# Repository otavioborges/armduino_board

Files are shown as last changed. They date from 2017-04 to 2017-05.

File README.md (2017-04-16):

# ARMduino

ARMduino is an open-source + open-hardware project. Created to be a stepping stone from Arduino development boards to ARM development.

The board feature the same pinout as an Arduino UNO&trade; and same voltage levels on target.

## Board Description

### Power source

The board feature automatic source selection using a LM385 and P-MOSFET (same arrangement as Arduino UNO&trade;). External power range goes from 6~30VDC. Max current supported 0.5A.

### Programmer/Debugger

A MKL26Z32VFM4, using an adapted [DAPLink](https://github.com/mbedmicro/DAPLink) source-code (available on https://bitbucket.org/otavioborges/daplink-if, is used as programmer/debugger through openOCD interface.

### Target

The NXP's MKE02Z64VLD4 replaces the usual ATMEGA8U2 from Arduino. Providing:
 * Enhanced operation frequency (up to 20MHz Bus and core);
 * More flexibility on pin muxing (available on [KE02 Sub-family Data Sheet](http://www.nxp.com/assets/documents/data/en/data-sheets/MKE02P64M20SF0.pdf);
 * SPI, I2C, UART, PWM and ADC peripheral access through break-out connections;
 * I/O signal and periodic interrupts;
 * Debugging capabilities, using MKL26, GDB, DAPLink and openOCD;
 * Up to two breakpoints;
 
### Pinout

The same pin voltage and placement used in Arduino UNO&trade; is available. Furthermore, as NXP MCU provide a range of pin-multiplexing pin-assignment can be altered to fit user's desire.

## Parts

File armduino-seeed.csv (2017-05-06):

Part/Designator | Manufacture Part Number/Seeed SKU | Quantity
S1 | SKHHAJA010 | 1
C1, C6, C11, C12, C15 | GRM21BR71E104KA01L | 5
R4, R9, R11, R13, R14, R19 | RC0805FR-0710KL | 6
C3, C4 | 106CKR063M | 2
IOH | 61301011821 | 1
R1, R6, R8, R15, R16, R17, R20 | RC0805JR-07120RL | 7
R5, R12 | RC0805FR-071M02L | 2
D1 | VSSA210-M3/5AT | 1
C5, C20 | GRM216R71H102KA01D | 2
C9, C10, C17 | GRM21BR61C105KA01L | 3
C18 | GRM216R71H222JA01D | 1
Q2 | ABLS-5.000MHZ-B4-T | 1
R7, R10 | RC0805JR-0720KL | 2
C13, C14, C16, C19 | GRM1885C1H220JA01D | 4
C2 | C2012X7R1H334K125AA | 1
R2, R3 | ERJ-6ENF33R0V | 2
ICSP1, ICSP2 | 4-146262-1 | 2
R18 | ERJ-6GEYJ472V | 1
AD | 929870-01-06-RA | 1
IC1 | LD1117DT50TR | 1
Q3 | ABL-8.000MHZ-B2 | 1
IOL, POWER | 960108-6303-AR | 2
LED1 | 150080BS75000 | 1
Q1 | FDN360P | 1
POWER_LED | APT2012SGC | 1
IC3 | IFX1117ME V33 | 1
IC2 | LM358DT | 1
U2 | MKE02Z64VLD4 | 1
U1 | MKL26Z128VFM4 | 1
X1 | PJ-002A | 1
FUSE1 | 0ZCG0050AF2C | 1
X2 | 61400416121 | 1
CONN, RUN, RX, TX, USB | APT2012YC | 5

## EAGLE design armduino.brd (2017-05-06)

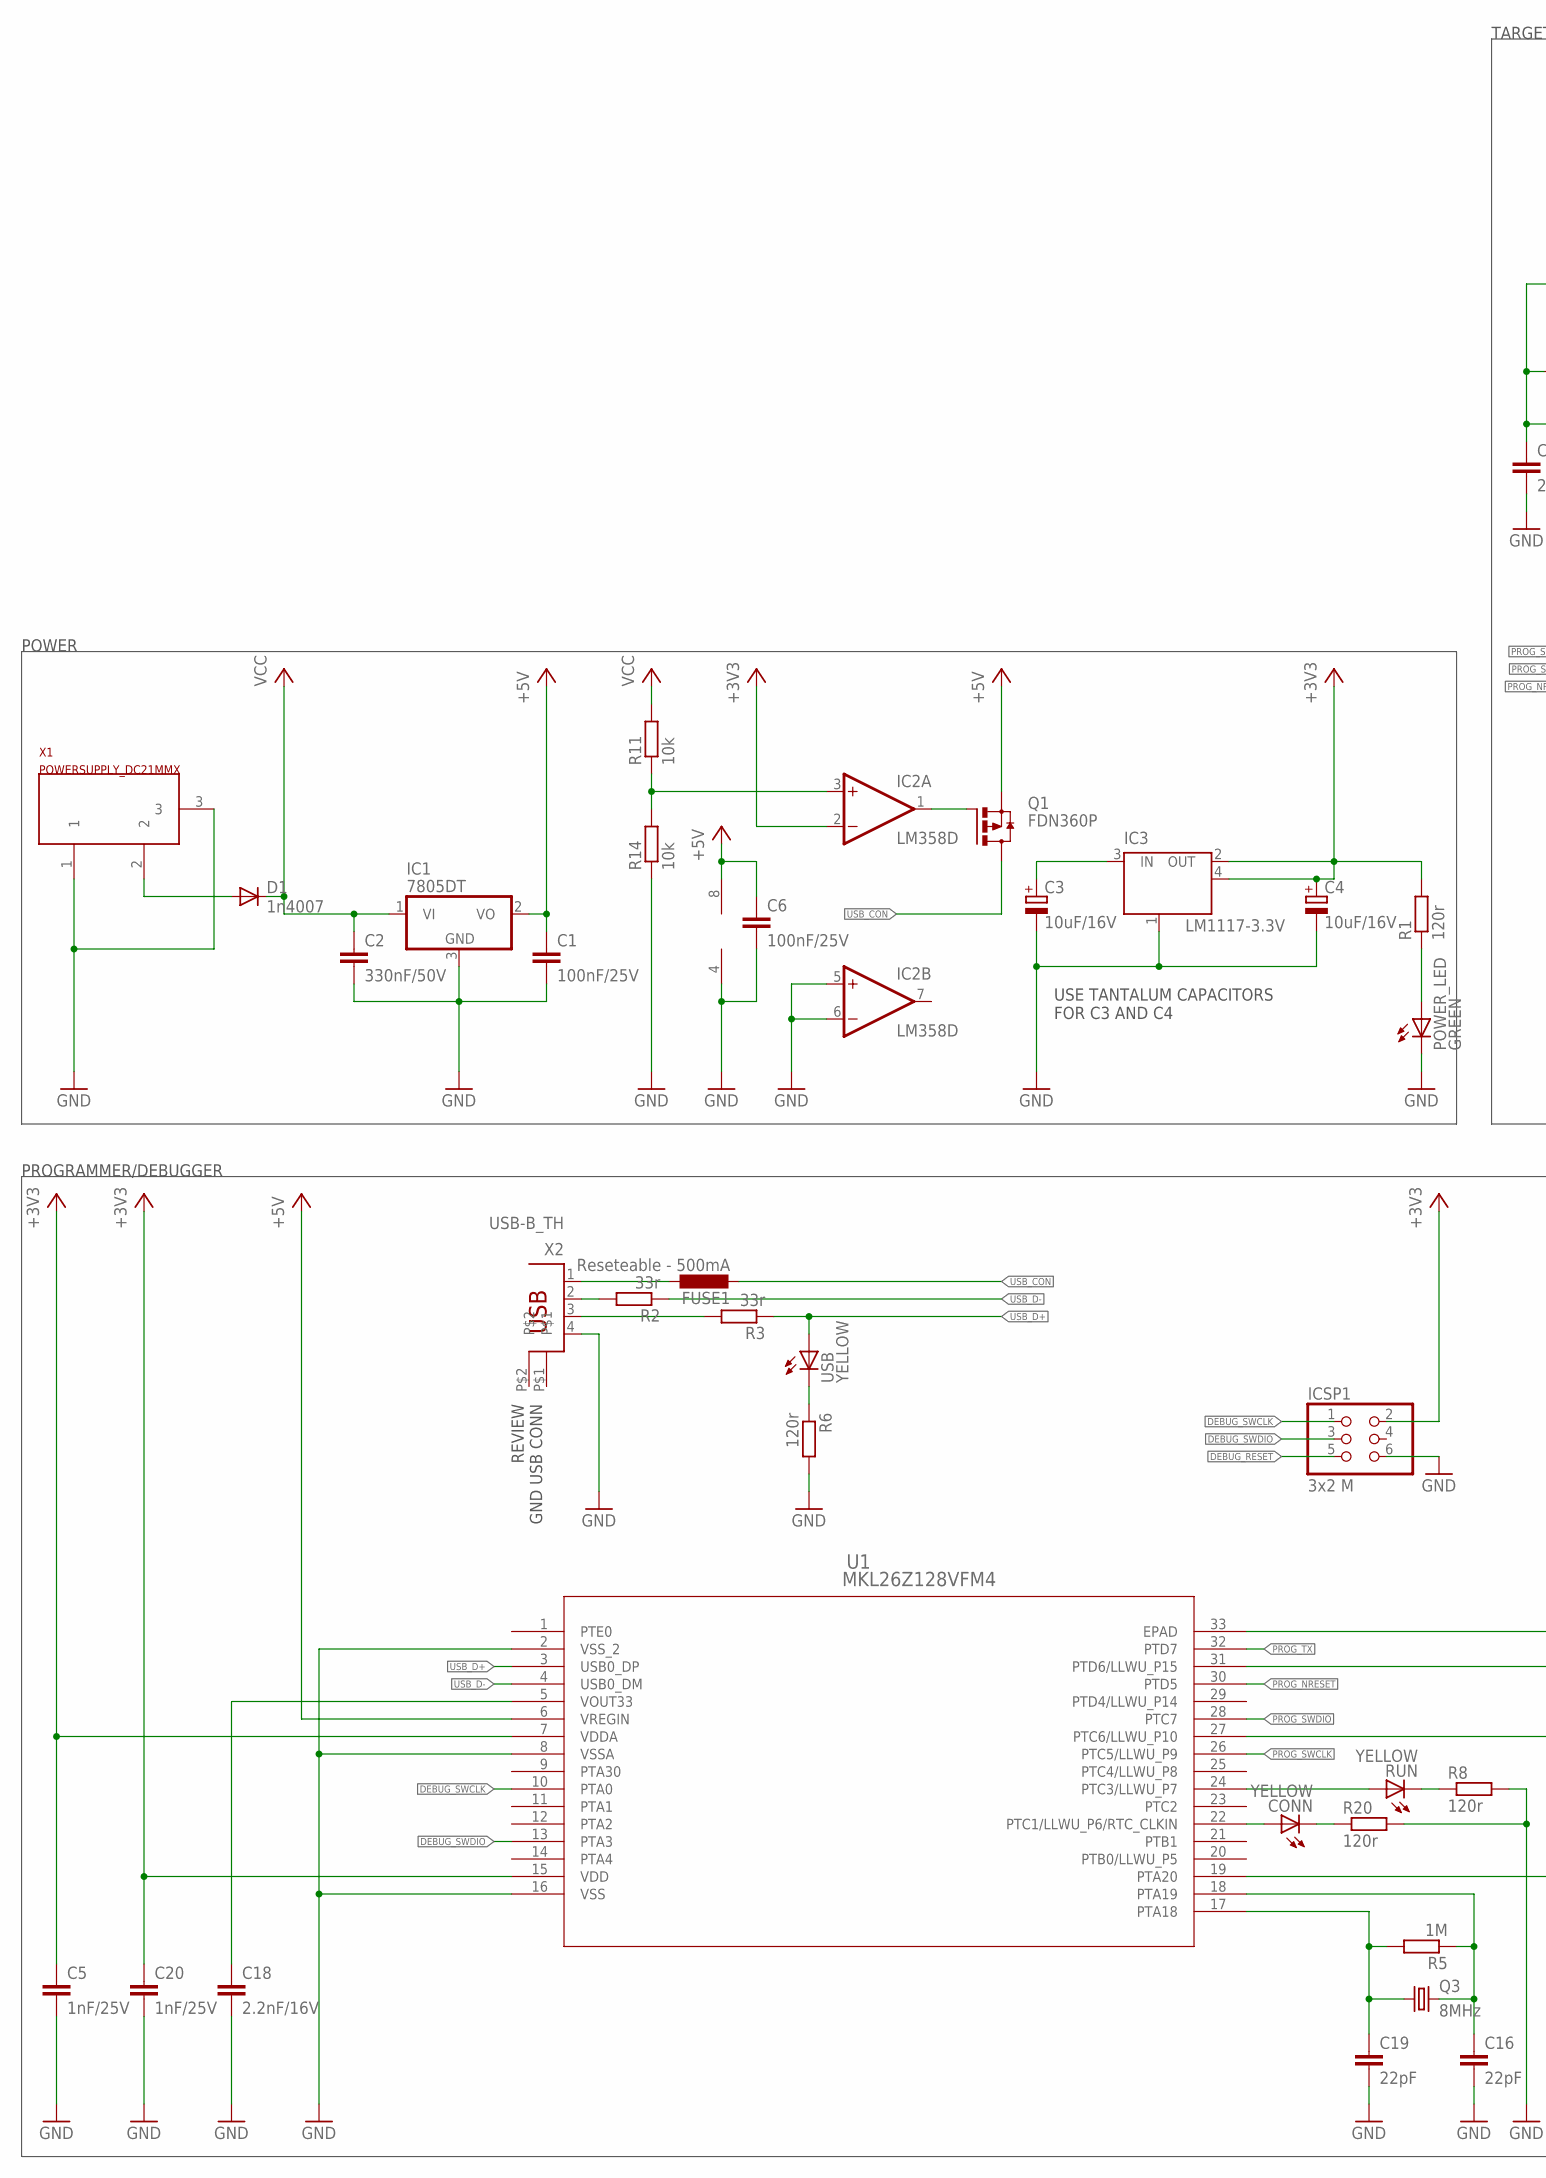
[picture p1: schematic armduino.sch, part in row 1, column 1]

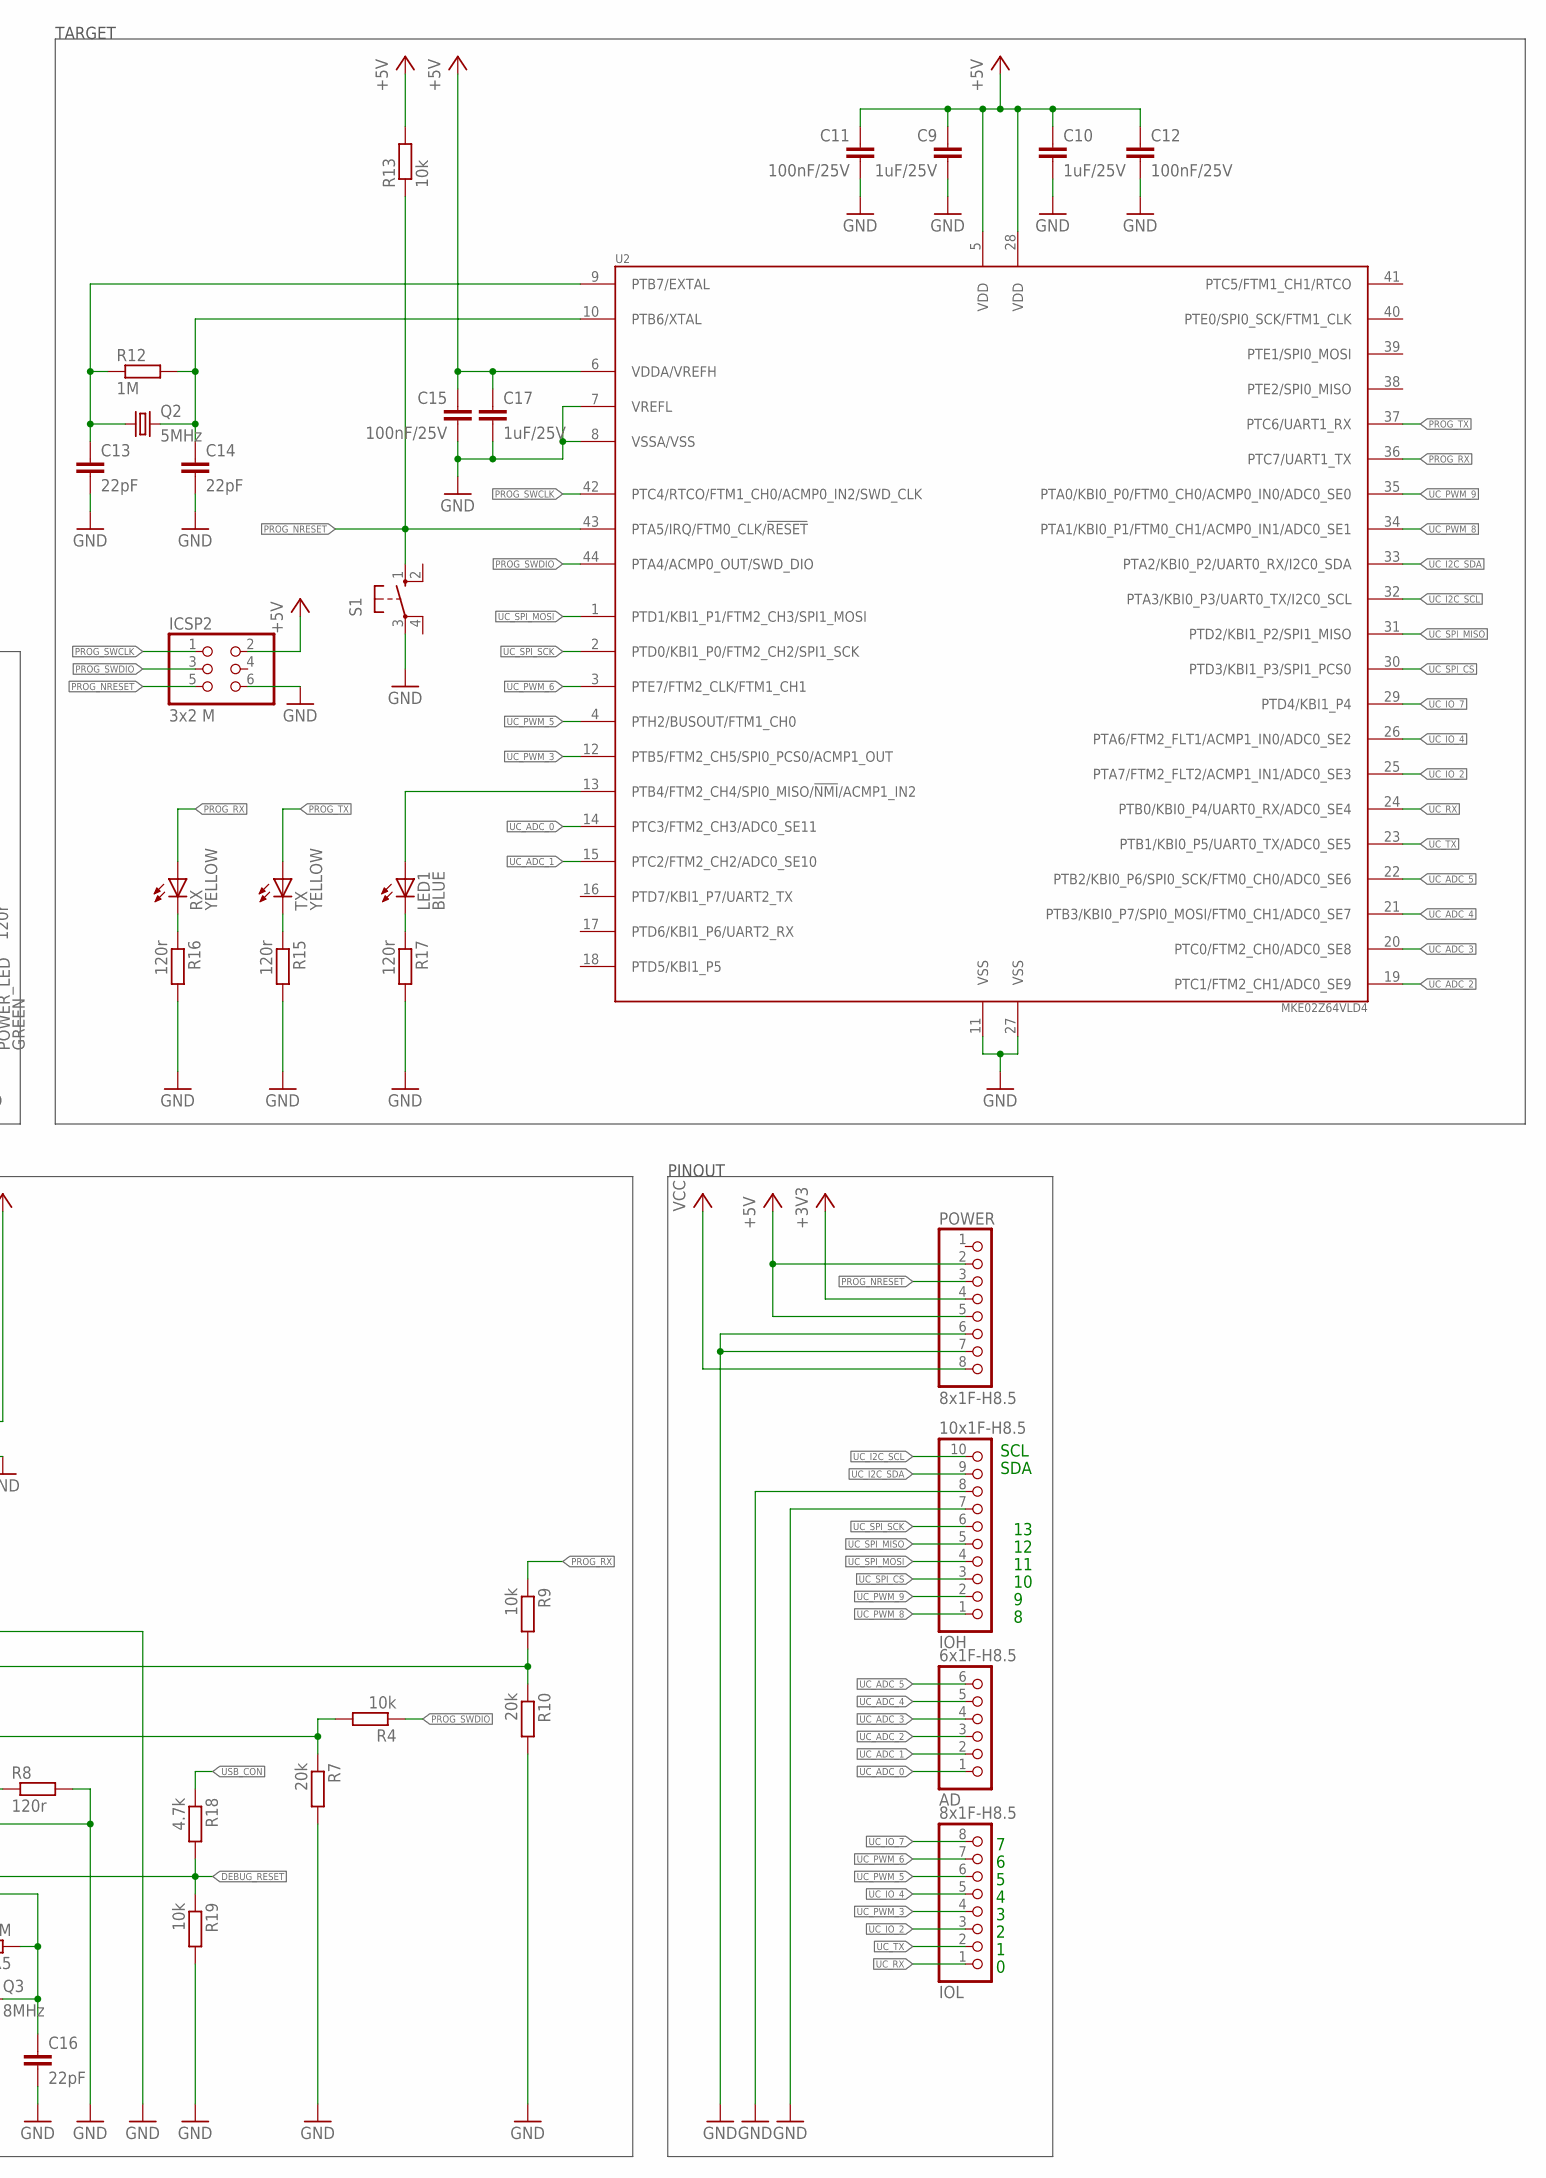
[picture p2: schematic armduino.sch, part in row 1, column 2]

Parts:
AD: 6x1F-H8.5; 1X06
C1, C6, C11, C12, C15: 100nF/25V; C0805K
C2: 330nF/50V; C0805K
C3, C4: 10uF/16V; E2-4
C5, C20: 1nF/25V; C0805K
C9, C10, C17: 1uF/25V; C0805K
C13, C14, C16, C19: 22pF; C0603K
C18: 2.2nF/16V; C0805K
CONN: YELLOW; CHIP-LED0805
D1: 1n4007; DO-214AC
FUSE1: Reseteable - 500mA; L1812
IC1: 7805DT; TO252
IC2: LM358D; SO08
IC3: LM1117-3.3V; SOT223
ICSP1, ICSP2: 3x2 M; 2X03
IOH: 10x1F-H8.5; 1X10
IOL: 8x1F-H8.5; 1X08
LED1: BLUE; CHIP-LED0805
POWER: 8x1F-H8.5; 1X08
POWER_LED: GREEN; CHIP-LED0805
Q1: FDN360P; SUPER-SOT3
Q2: 5MHz; SM49
Q3: 8MHz; HC49/S
R1, R6, R8, R15, R16, R17, R20: 120r; M0805
R2, R3: 33r; M0805
R4, R9, R11, R13, R14, R19: 10k; M0805
R5, R12: 1M; M0805
R7, R10: 20k; M0805
R18: 4.7k; M0805
RUN: YELLOW; CHIP-LED0805
RX: YELLOW; CHIP-LED0805
S1: 10-XX; B3F-10XX
TX: YELLOW; CHIP-LED0805
U1: MKL26Z128VFM4; QFN-32_5X5X0.9
U2: MKE02Z64VLD4; QFP44
USB: YELLOW; CHIP-LED0805
X1: POWERSUPPLY_DC21MMX; POWERSUPPLY_DC-21MM
X2: USB-B_TH; PN61729

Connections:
+3V3: C4.+, C5.1, C20.1, IC2.2 (-IN), IC3.2 (OUT), IC3.4 (OUT), ICSP1.2, POWER.4, R1.2, U1.7 (VDDA), U1.15 (VDD)
+5V: C1.1, C6.1, C9.1, C10.1, C11.1, C12.1, C15.1, C17.1, IC1.2 (VO), IC2.8 (V+), ICSP2.2, POWER.2, POWER.5, Q1.2 (S), R13.2, U1.6 (VREGIN), U2.5 (VDD), U2.6 (VDDA/VREFH), U2.28 (VDD)
CONN: CONN.C, R20.1
DEBUG_RESET: ICSP1.5, R18.2, R19.1, U1.19 (PTA20)
DEBUG_SWCLK: ICSP1.1, U1.10 (PTA0)
DEBUG_SWDIO: ICSP1.3, U1.13 (PTA3)
GND: C1.2, C2.2, C3.-, C4.-, C5.2, C6.2, C9.2, C10.2, C11.2, C12.2, C13.2, C14.2, C15.2, C16.2, C17.2, C18.2, C19.2, C20.2, IC1.3 (GND), IC2.4 (V-), IC2.5 (+IN), IC2.6 (-IN), IC3.1 (GND/ADJ), ICSP1.6, ICSP2.6, IOH.7, IOH.8, POWER.6, POWER.7, POWER_LED.C, R6.2, R7.2, R8.2, R10.2, R14.1, R15.2, R16.2, R17.2, R19.2, R20.2, S1.3, U1.2 (VSS_2), U1.8 (VSSA), U1.16 (VSS), U1.33 (EPAD), U2.7 (VREFL), U2.8 (VSSA/VSS), U2.11 (VSS), U2.27 (VSS), X1.1, X1.3, X2.4
unnamed: D1.A, X1.2
unnamed: POWER_LED.A, R1.1
unnamed: FUSE1.1, X2.1
unnamed: R2.2, X2.2
unnamed: R6.1, USB.C
unnamed: R9.2, R10.1, U1.31 (PTD6/LLWU_P15)
unnamed: R3.2, X2.3
unnamed: R4.2, R7.1, U1.27 (PTC6/LLWU_P10)
unnamed: C3.+, IC3.3 (IN)
unnamed: C18.1, U1.5 (VOUT33)
unnamed: R8.1, RUN.C
unnamed: RUN.A, U1.24 (PTC3/LLWU_P7)
unnamed: CONN.A, U1.22 (PTC1/LLWU_P6/RTC_CLKIN)
unnamed: IC2.3 (+IN), R11.1, R14.2
unnamed: C14.1, Q2.2, R12.2, U2.10 (PTB6/XTAL)
unnamed: C13.1, Q2.1, R12.1, U2.9 (PTB7/EXTAL)
unnamed: R15.1, TX.C
unnamed: R16.1, RX.C
unnamed: LED1.A, U2.13 (PTB4/FTM2_CH4/SPI0_MISO/!NMI!/ACMP1_IN2)
unnamed: LED1.C, R17.1
unnamed: C19.1, Q3.1, R5.2, U1.17 (PTA18)
unnamed: C16.1, Q3.2, R5.1, U1.18 (PTA19)
unnamed: IC2.1 (OUT), Q1.1 (G)
PROG_NRESET: ICSP2.5, POWER.3, R13.1, S1.1 (S), U1.30 (PTD5), U2.43 (PTA5/IRQ/FTM0_CLK/!RESET)
PROG_RX: R9.1, RX.A, U2.36 (PTC7/UART1_TX)
PROG_SWCLK: ICSP2.1, U1.26 (PTC5/LLWU_P9), U2.42 (PTC4/RTCO/FTM1_CH0/ACMP0_IN2/SWD_CLK)
PROG_SWDIO: ICSP2.3, R4.1, U1.28 (PTC7), U2.44 (PTA4/ACMP0_OUT/SWD_DIO)
PROG_TX: TX.A, U1.32 (PTD7), U2.37 (PTC6/UART1_RX)
UC_ADC_0: AD.1, U2.14 (PTC3/FTM2_CH3/ADC0_SE11)
UC_ADC_1: AD.2, U2.15 (PTC2/FTM2_CH2/ADC0_SE10)
UC_ADC_2: AD.3, U2.19 (PTC1/FTM2_CH1/ADC0_SE9)
UC_ADC_3: AD.4, U2.20 (PTC0/FTM2_CH0/ADC0_SE8)
UC_ADC_4: AD.5, U2.21 (PTB3/KBI0_P7/SPI0_MOSI/FTM0_CH1/ADC0_SE7)
UC_ADC_5: AD.6, U2.22 (PTB2/KBI0_P6/SPI0_SCK/FTM0_CH0/ADC0_SE6)
UC_I2C_SCL: IOH.10, U2.32 (PTA3/KBI0_P3/UART0_TX/I2C0_SCL)
UC_I2C_SDA: IOH.9, U2.33 (PTA2/KBI0_P2/UART0_RX/I2C0_SDA)
UC_IO_2: IOL.3, U2.25 (PTA7/FTM2_FLT2/ACMP1_IN1/ADC0_SE3)
UC_IO_4: IOL.5, U2.26 (PTA6/FTM2_FLT1/ACMP1_IN0/ADC0_SE2)
UC_IO_7: IOL.8, U2.29 (PTD4/KBI1_P4)
UC_PWM_3: IOL.4, U2.12 (PTB5/FTM2_CH5/SPI0_PCS0/ACMP1_OUT)
UC_PWM_5: IOL.6, U2.4 (PTH2/BUSOUT/FTM1_CH0)
UC_PWM_6: IOL.7, U2.3 (PTE7/FTM2_CLK/FTM1_CH1)
UC_PWM_8: IOH.1, U2.34 (PTA1/KBI0_P1/FTM0_CH1/ACMP0_IN1/ADC0_SE1)
UC_PWM_9: IOH.2, U2.35 (PTA0/KBI0_P0/FTM0_CH0/ACMP0_IN0/ADC0_SE0)
UC_RX: IOL.1, U2.24 (PTB0/KBI0_P4/UART0_RX/ADC0_SE4)
UC_SPI_CS: IOH.3, U2.30 (PTD3/KBI1_P3/SPI1_PCS0)
UC_SPI_MISO: IOH.5, U2.31 (PTD2/KBI1_P2/SPI1_MISO)
UC_SPI_MOSI: IOH.4, U2.1 (PTD1/KBI1_P1/FTM2_CH3/SPI1_MOSI)
UC_SPI_SCK: IOH.6, U2.2 (PTD0/KBI1_P0/FTM2_CH2/SPI1_SCK)
UC_TX: IOL.2, U2.23 (PTB1/KBI0_P5/UART0_TX/ADC0_SE5)
USB_CON: FUSE1.2, Q1.3 (D), R18.1
USB_D+: R3.1, U1.3 (USB0_DP), USB.A
USB_D-: R2.1, U1.4 (USB0_DM)
VCC: C2.1, D1.C, IC1.1 (VI), POWER.8, R11.2

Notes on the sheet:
SDA
SCL
REVIEW GND USB CONN
USE TANTALUM CAPACITORS FOR C3 AND C4
PROGRAMMER/DEBUGGER
PINOUT
POWER
TARGET

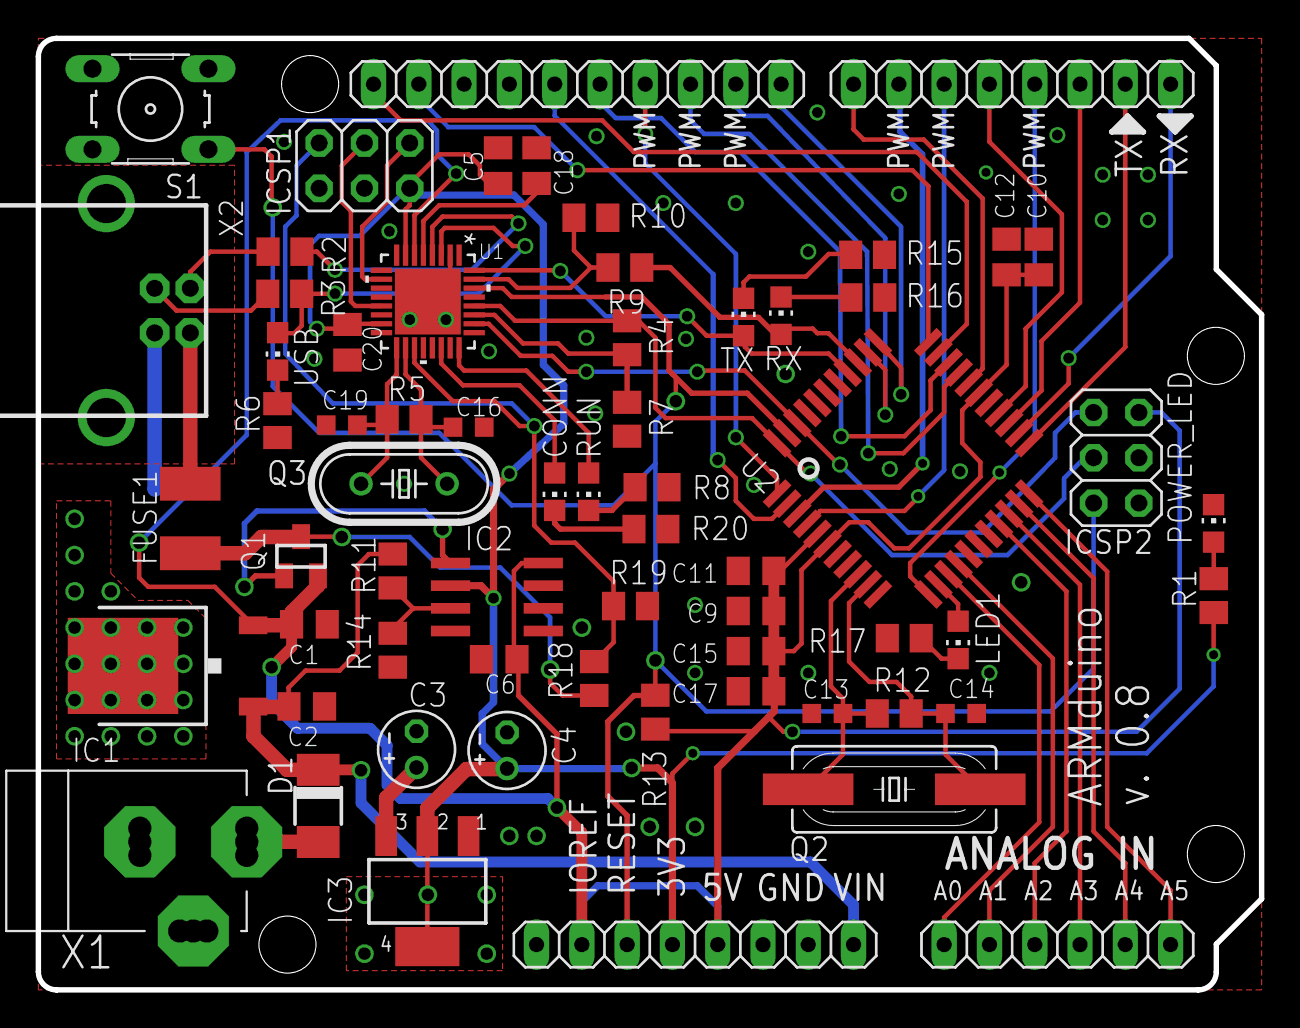
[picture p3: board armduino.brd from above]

Board: 2 copper layers, 68.6 x 53.4 mm, 64 parts (0 on the bottom side), 61 nets.

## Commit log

2017-04-11 Version 0.2
    [armduino.brd, armduino.sch]
2017-04-11 Version 0.4
    [armduino.brd, armduino.sch]
2017-04-11 Removed PWM 3 and 5 from FTM0_FLT pins.
    Some pins were moved around to fit PWM on FTM_CHx pins.
    [armduino.brd, armduino.sch]
2017-04-11 Correct voltage source selection, correct target XTAL.
    * Add LM358 to switch between external connector and USB source;
    * Target using 20MHz external crystal;
    * Re-route to fit new components;
    [armduino.brd, armduino.sch]
2017-04-11 Fix version printed on board
    [armduino.brd]
2017-04-16 Modifications to v0.7: * Schematic parts grouped together; * KL26 footprint edited with extended pads, for easier soldering; * SWD signal rerouting to avoid transpositions and unnecessary curves; * A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
    [armduino.brd, armduino.sch]
2017-04-26 Add led values according to colors to be used and fuse value.
    [armduino.brd, armduino.sch]
2017-04-26 Fixed target XTAL value, heat dissipation mask, update to version 0.7
    [armduino.brd, armduino.sch]
2017-04-26 Fixed 100nF caps to same value.
    [armduino.brd, armduino.sch]
2017-04-26 Add seeed BOM.
    [armduino-seeed.csv]
2017-05-06 Added dimentions
    [armduino-seeed.csv, armduino.brd]
